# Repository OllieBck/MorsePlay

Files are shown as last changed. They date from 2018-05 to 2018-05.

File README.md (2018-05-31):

# MorsePlay

MorsePlay uses the [Morse GBoard](https://support.google.com/accessibility/android/answer/9011881) on Android devices to activate switch adapted toys and similar interfaces via a pluggable Bluetooth Low Energy (BLE) module.

It is developed by the [Adaptive Design Association](http://www.adaptivedesign.org/) and [NottLimited](http://www.tandemmaster.org/home.html).

To see a demo of the project, visit https://youtu.be/Mf9dzT8w3vc.

To see more about switch adapting mass produced toys, visit [DIYAbility.org](https://www.diyability.org/guide/switch-adapting-a-remote-control-toy/) as well as [GoBabyGo Cars](https://www.diyability.org/2014/11/go-baby-go-the-ultimate-toy-hack/) -- or to find out more about [GoBabyGo](https://sites.udel.edu/gobabygo/).

The project comes in 3 parts on this repo.

["MorsePlay -- App"](https://github.com/OllieBck/MorsePlay/tree/master/MorsePlay--App) modifies an example from Don Coleman's [Cordova BLE Central Library](https://github.com/don/cordova-plugin-ble-central).

["MorsePlay -- BLE_Module"](https://github.com/OllieBck/MorsePlay/tree/master/MorsePlay--BLE_Module) utilizes a RedBear Labs BLE Nano V2 and is built off an [example](https://github.com/RedBearLab/arduino-BLEPeripheral/tree/master/examples/SimpleChat) the lab created of Sandeep Mistry's [Arduino BLE Peripheral](https://github.com/sandeepmistry/arduino-BLEPeripheral) library.

["MorsePlay -- Schematics"](https://github.com/OllieBck/MorsePlay/tree/master/MorsePlay%20-%20Schematics) include the Eagle files for the simple circuit for the BLE module relay board.

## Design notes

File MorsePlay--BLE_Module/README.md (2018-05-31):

# MorsePlay BLE module

To install the firmware for the BLE module, you will need a [RedBearLab Nano V2](https://www.seeedstudio.com/RedBear-BLE-Nano-Kit-V2--p-2836.html).

You will need to ensure [Arduino](https://www.arduino.cc/en/Main/Software) is installed.

Next, configure the device following Sandeep Mistry's [Arduino NRF5 Core](https://github.com/sandeepmistry/arduino-nRF5) to make it programmable by Arduino.

This will allow you to add the RedBear Nano V2 to your board list.

Mistry's Arduino [BLE Peripheral library](https://github.com/sandeepmistry/arduino-BLEPeripheral) is then used.

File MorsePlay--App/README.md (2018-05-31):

# MorsePlay Cordova App

Open up Android device and go to "Settings > About device".

Find the "Build number" and click on that repeatedly until you enter developer mode.

Install the [Cordova Command Line Tool](https://cordova.apache.org/docs/en/latest/guide/cli/).

Download the repo, open Terminal, and `cd` into the `MorsePlay--App` folder.

```
cd MorsePlay--App
```

Add the Android platform by typing:

```
cordova platform add android
```

Add the BLE Central Plugin by typing:

```
cordova plugin add cordova-plugin-ble-central
```

Upload the app to the Android device.

```
cordova run android
```

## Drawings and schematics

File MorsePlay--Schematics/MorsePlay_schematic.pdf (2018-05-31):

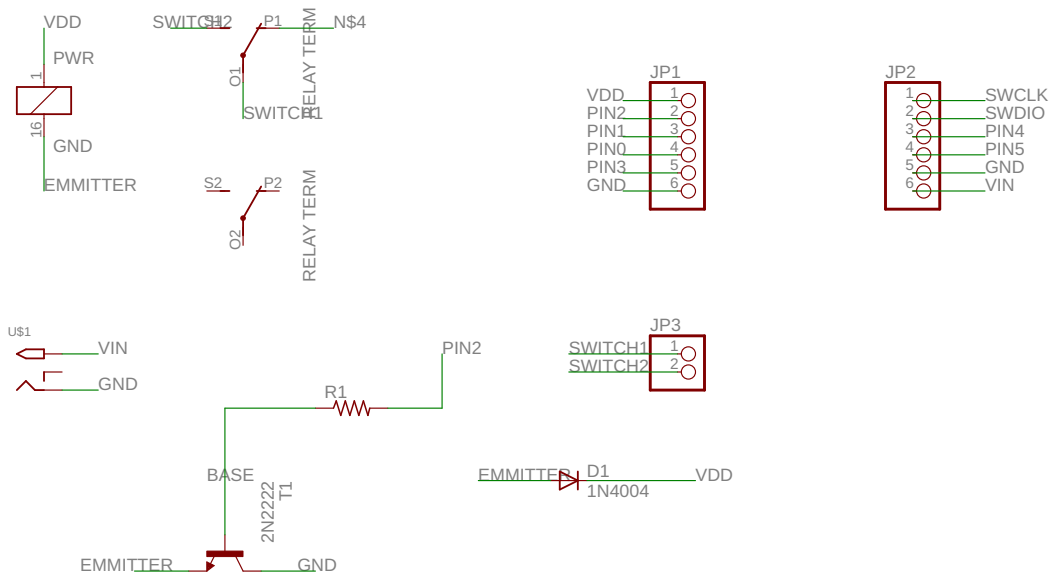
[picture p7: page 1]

2N22221N4004JP1123456 JP2123456 JP312 R1 T1 D1 GND PWR 16 1 RELAY TERM O1 S1 P1 RELAY TERM O2 S2 P2 U$1 VDD VDD VDD PIN2 PIN2 PIN1 PIN0 PIN3 GND GND GND GND SWCLK SWDIO PIN4 PIN5 VIN VIN SWITCH1 SWITCH1 SWITCH2 SWITCH2 BASE EMMITTER EMMITTER EMMITTER N$4

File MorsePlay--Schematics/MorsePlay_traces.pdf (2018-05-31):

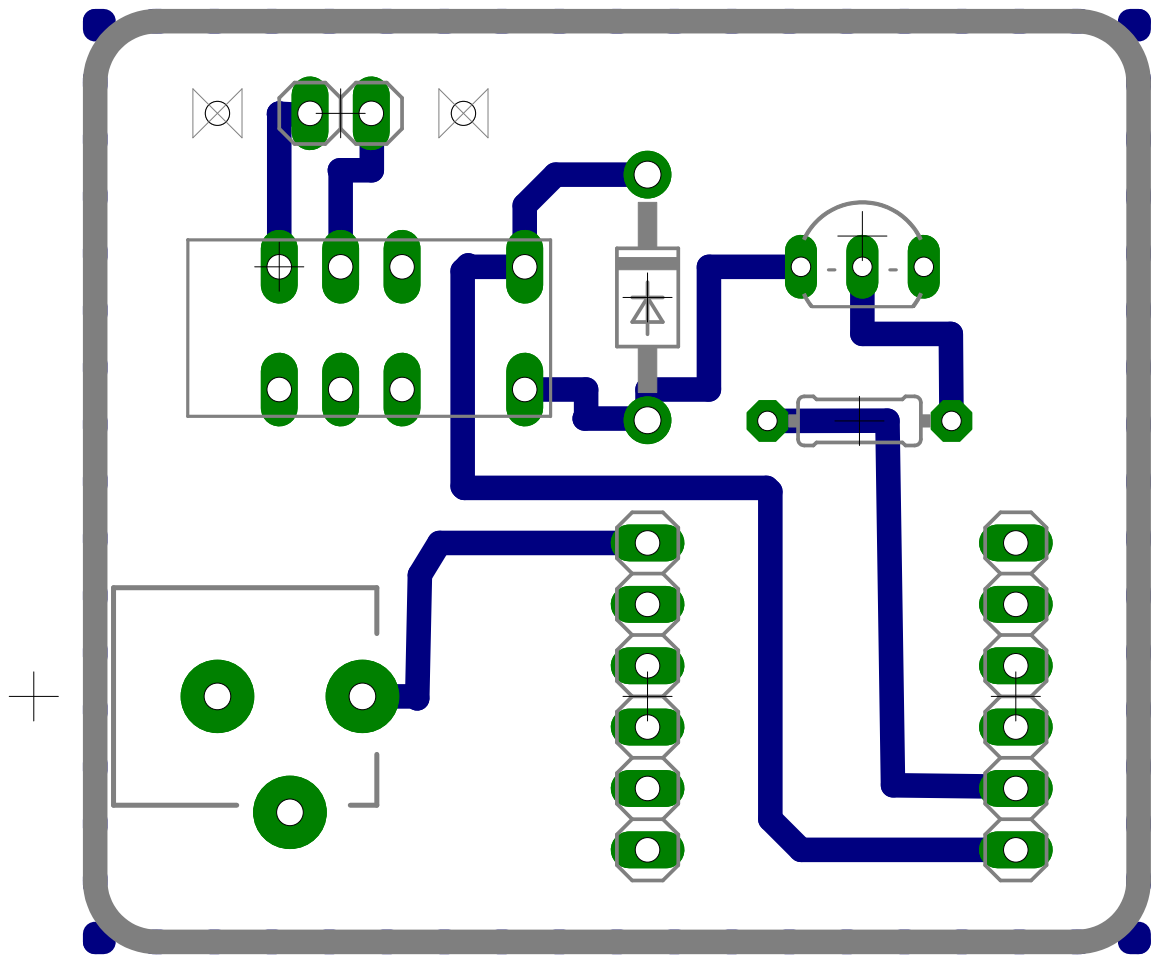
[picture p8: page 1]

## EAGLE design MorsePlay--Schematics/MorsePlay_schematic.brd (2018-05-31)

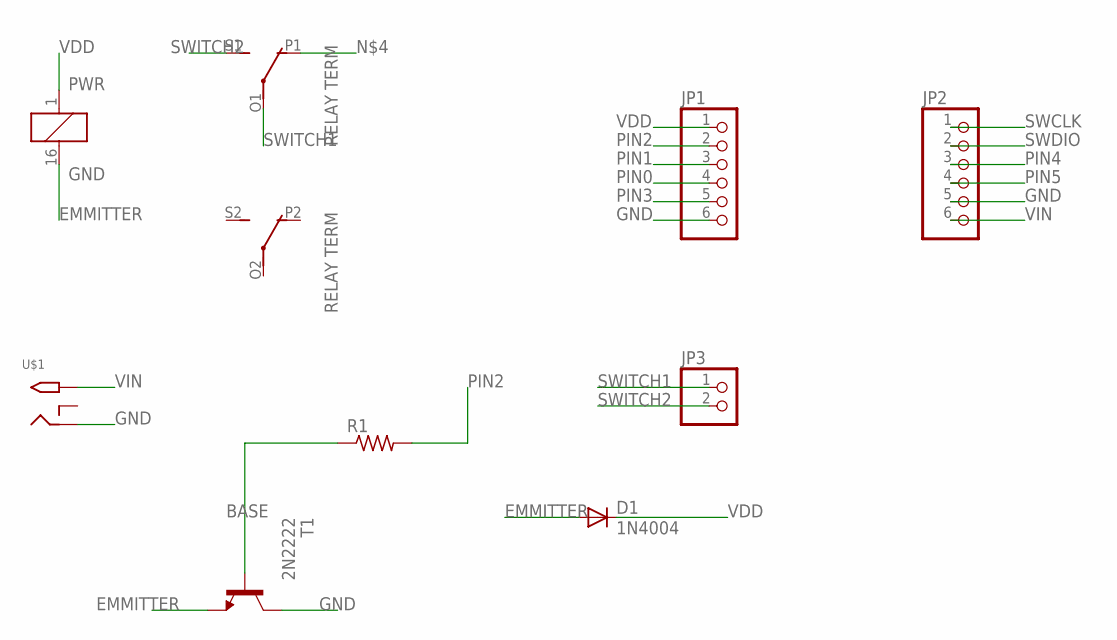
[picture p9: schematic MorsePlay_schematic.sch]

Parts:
D1: 1N4004; DO41-10
JP1, JP2: PINHD-1X6; 1X06
JP3: PINHD-1X2; 1X02
R1: R-US_0204/7; 0204/7
RELAY1: RELAY_3VTERMINAL; 351
T1: 2N2222; TO92-EBC-OVAL
U$1: DCPOWERJACK; DCJACK_2MM_PTH

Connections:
BASE: R1.1, T1.B
EMMITTER: D1.A, RELAY1.16 (GND), T1.E
GND: JP1.6, JP2.5, T1.C, U$1.GND (RING)
PIN0: JP1.4
PIN1: JP1.3
PIN2: JP1.2, R1.2
PIN3: JP1.5
PIN4: JP2.3
PIN5: JP2.4
SWCLK: JP2.1
SWDIO: JP2.2
SWITCH1: JP3.1, RELAY1.O1 (COM)
SWITCH2: JP3.2, RELAY1.S1 (NO)
VDD: D1.C, JP1.1, RELAY1.1 (PWR)
VIN: JP2.6, U$1.PWR (TIP)

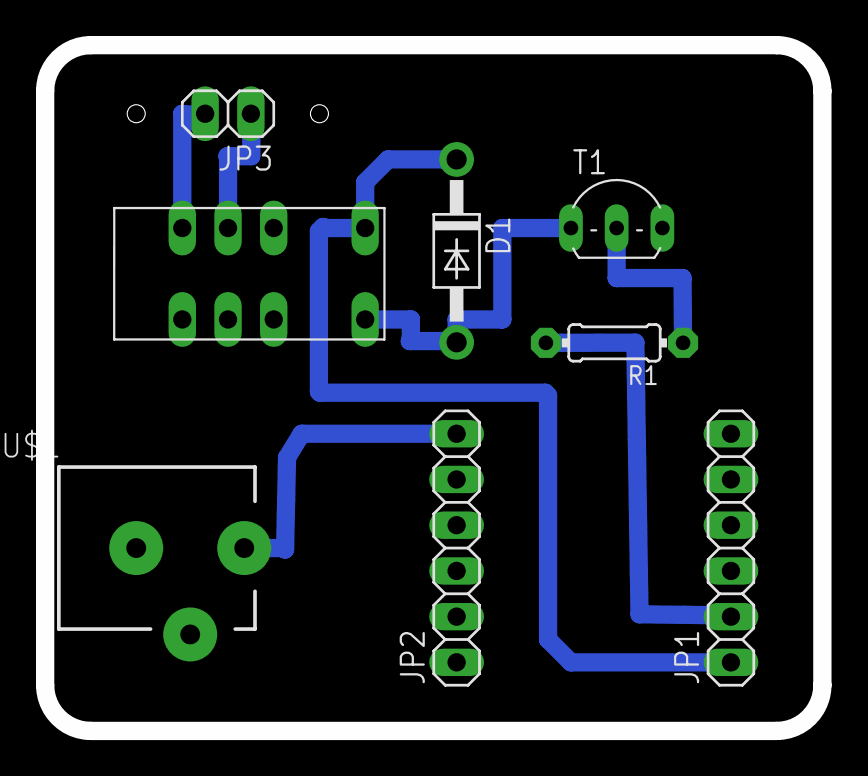
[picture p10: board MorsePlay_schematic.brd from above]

Board: 2 copper layers, 43.2 x 38.1 mm, 8 parts (0 on the bottom side), 8 nets.

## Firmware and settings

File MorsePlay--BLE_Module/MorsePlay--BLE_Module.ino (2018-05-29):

/*
Copyright (c) 2012-2014 RedBearLab
Permission is hereby granted, free of charge, to any person obtaining a copy of this software and associated documentation files (the "Software"), to deal in the Software without restriction, including without limitation the rights to use, copy, modify, merge, publish, distribute, sublicense, and/or sell copies of the Software, and to permit persons to whom the Software is furnished to do so, subject to the following conditions:
The above copyright notice and this permission notice shall be included in all copies or substantial portions of the Software.
THE SOFTWARE IS PROVIDED "AS IS", WITHOUT WARRANTY OF ANY KIND, EXPRESS OR IMPLIED, INCLUDING BUT NOT LIMITED TO THE WARRANTIES OF MERCHANTABILITY, FITNESS FOR A PARTICULAR PURPOSE AND NONINFRINGEMENT. IN NO EVENT SHALL THE AUTHORS OR COPYRIGHT HOLDERS BE LIABLE FOR ANY CLAIM, DAMAGES OR OTHER LIABILITY, WHETHER IN AN ACTION OF CONTRACT, TORT OR OTHERWISE, ARISING FROM, OUT OF OR IN CONNECTION WITH THE SOFTWARE OR THE USE OR OTHER DEALINGS IN THE SOFTWARE.
*/

/*
 *    Chat
 *
 *    Simple chat sketch, work with the BLEController iOS/Android App.
 *    Type something from the Arduino serial monitor to send
 *    to the BLEController App or vice verse.
 *    Characteristics received from App will print on Serial Monitor.
 * 
 * Modified by Jason Beck @ Adaptive Design Association for use in MorsePlay code demo.
 */
 
// Import libraries (BLEPeripheral depends on SPI)
#include <SPI.h>
#include <BLEPeripheral.h>

// define pins (varies per shield/board)
#define BLE_REQ   6
#define BLE_RDY   7
#define BLE_RST   4

const int triggerPin = 2; // pin connected via resistor to transistor to trigger 3V relay

/*----- BLE Utility -------------------------------------------------------------------------*/
// create peripheral instance, see pinouts above
BLEPeripheral            blePeripheral        = BLEPeripheral(BLE_REQ, BLE_RDY, BLE_RST);

// create service
BLEService               uartService          = BLEService("713d0000503e4c75ba943148f18d941e"); //UUID for service
// create characteristic
BLECharacteristic    txCharacteristic = BLECharacteristic("713d0002503e4c75ba943148f18d941e", BLENotify, 20); // UUID for sending out info
BLECharacteristic    rxCharacteristic = BLECharacteristic("713d0003503e4c75ba943148f18d941e", BLEWriteWithoutResponse, 20); // UUID for receiving info
/*--------------------------------------------------------------------------------------------*/

void setup()
{  
  Serial.begin(115200);
#if defined (__AVR_ATmega32U4__)
  //Wait until the serial port is available (useful only for the Leonardo)
  //As the Leonardo board is not reseted every time you open the Serial Monitor
  while(!Serial) {}
  delay(3000);  //5 seconds delay for enabling to see the start up comments on the serial board
#endif

/*----- BLE Utility ---------------------------------------------*/
  // set advertised local name and service UUID
  blePeripheral.setLocalName("MorsePlay"); // used to find the BLE device and automatically connect
  blePeripheral.setAdvertisedServiceUuid(uartService.uuid());

  // add service and characteristic
  blePeripheral.addAttribute(uartService);
  blePeripheral.addAttribute(rxCharacteristic);
  blePeripheral.addAttribute(txCharacteristic);

  // begin initialization
  blePeripheral.begin();
/*---------------------------------------------------------------*/

  Serial.println(F("BLE UART Peripheral"));

  pinMode(triggerPin, OUTPUT);
  
}

unsigned char buf[16] = {0};
unsigned char len = 0;

void loop()
{
  BLECentral central = blePeripheral.central();

  if (central) 
  {
    // central connected to peripheral
    Serial.print(F("Connected to central: "));
    Serial.println(central.address());

    while (central.connected()) 
    {
      // central still connected to peripheral
      if (rxCharacteristic.written()) 
      {
        unsigned char len = rxCharacteristic.valueLength();
        const unsigned char *val = rxCharacteristic.value();
        Serial.print("didCharacteristicWritten, Length: "); 
        Serial.println(len, DEC);
        unsigned char i = 0;
        int triggerValue; // variable to hold data from mobile device
        while(i<len)
        {
          Serial.write(val[i++]);

          triggerValue = val[len-1]; // assign variable value of incoming data (should be the letter "f");

          if (triggerValue == 102){ // check to see if incoming data is equal to "f")
            digitalWrite(triggerPin, HIGH); // trigger relay
            delay(5000);
            triggerValue = 0; // reset variable
            digitalWrite(triggerPin, LOW); // deactivate relay
          }
        }
      }
      
      if ( Serial.available() )
      {
        delay(5);
        unsigned char len = 0;
        len = Serial.available(); 
        char val[len];
        Serial.readBytes(val, len);
        txCharacteristic.setValue((const unsigned char *)val, len);
      }
    }
    
    // central disconnected
    Serial.print(F("Disconnected from central: "));
    Serial.println(central.address());
  }
}
